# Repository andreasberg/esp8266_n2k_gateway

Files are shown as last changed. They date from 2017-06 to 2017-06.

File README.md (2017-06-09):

# NMEA2000 to WebSocket+Serial gateway 
Reads messages of N2K-bus and relaying over WebSocket and Serial 
### Functionality
- Listens for messages on NMEA 2000 (CANBus) bus and logs PGN of all messages received
- Writes same output over WebSocket and over Serial in Linux-'Tee'-like fashion (WebSocketBufferedStrem.h, inspired by [NeoTee](https://github.com/SlashDevin/NeoTee))
- Parses selected messages and logs
- Provides a simple yet (somewhat) responsive ([BootstrapV3](http://getbootstrap.com/)-based) web interface from the ESP8266 SPIFFS-filesystem
- Web-captive portal for configuration of WiFi-connecition
- Over-The-Air updates supported

### Dependencies
Depends on the following libraries (in addtion to the [`ESP8266 Core`](https://github.com/esp8266/Arduino) and [`Arduino IDE`](https://github.com/arduino/Arduino))
- [`arduinoWebSockets`](https://github.com/Links2004/arduinoWebSockets) - WebSocket Server and Client for Arduino
- [`CAN_BUS_Shield`](https://github.com/peppeve/CAN_BUS_Shield) - Can Bus Mcp2515 8/16 MHz oscillator 
- [`NMEA2000`](https://github.com/ttlappalainen/NMEA2000) - NMEA2000 library for Arduino 
- [`NMEA2000_mcp`](https://github.com/andreasberg/NMEA2000_mcp) - NMEA2000 library support for MCP2515 CAN bus controller. Forked version with added support for ESP8266 interrupts
- [`WiFiManager`](https://github.com/tzapu/WiFiManager) - ESP8266 WiFi Connection manager with web captive portal
- [`Arduino-Makefile-ESP`](https://github.com/andreasberg/Arduino-Makefile-ESP) - Arduino Makefile for ESP-boards 

### Building & flashing 

Edit the Makefile 
```make
  ARDMK_DIR := $(SRCDIR)/../Arduino-Makefile-ESP
  BOARD_TAG=huzzah
  ESP_OTA_ADDR=192.168.12.31
```
Then compile->link->hex
```sh
  make 
```
Normal upload (`esptool`) over USB-serial-FTDI 
```sh
  # first hit GPIO0+RST buttons on the Huzzah-board to enter flash-mode
  make upload 
  # sometimes the boot process hangs after upload, press RST to try again 
```
If the device for the USB-serial port in not detected correctly then override by defining MONITOR_PORT in Makefile
```make
  MONITOR_PORT=/dev/tty.usbserial-A104OFNV
```
A special target `monitor` in the makefile opens a screen-connection over serial
```sh
  make monitor
  # Ctrl-A k let's you terminate the serial connection
  # Connection needs to be terminated before 'make upload' or 'make upload_fs'
```
Once this (or any other sketch supporing Over-The-Air (OTA) updates) is successfully flashed, further uploads can be done with `espota.py` without putting board into flash-mode or closing serial connection(monitor)
Update Makefile:
```make
  ESP_OTA_ADDR=192.168.4.1
  ESP_OTA_PORT=8080           (default 8266)
  ESP_OTA_PWD=mysecret        (default <empty>)
```
and then
```sh
  make upload_ota
```
The webserver-files are located in [$(SRCDIR)/data](data) and the SPIFFS-file (filesystem binary image file) is created with makefile target `fs`
```sh
  make fs
```
and uploaded/flashed with
```sh
  make upload_fs
```
or
```sh
  make upload_fs_ota
```

After the board has booted and connected to Wifi, open a browser and go to `http://<IP>/index.html`

Default WebSocket-port is 81 so clicking 'Connect' shoud open the WebSocket-connection and start the feed of log-messages.

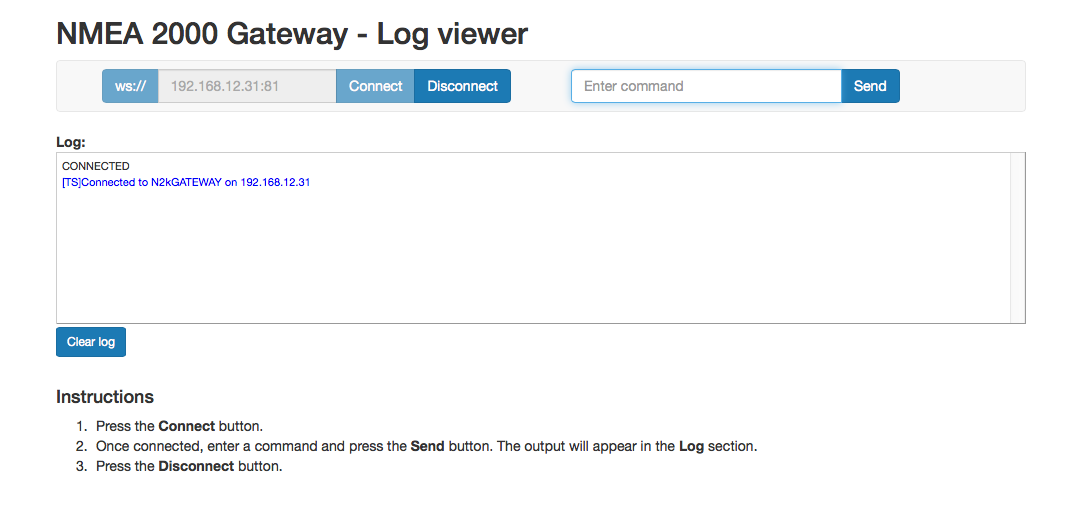
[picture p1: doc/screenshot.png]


### Hardware

The ESP-module used is the [Adafruit HUZZAH ESP8266 breakout](https://learn.adafruit.com/adafruit-huzzah-esp8266-breakout/overview) with a "shield" providing
  - a CAN-bus interface (based on Microchip MCP2515- & MCP2562-ICs)
  - a switching regulator (based on Texas Instrument TPS54202-IC) for powering both the ESP8266-module and shield from the standard 12V supply of NMEA2000 bus

The schematic&board (EAGLE-)files can be found [here](hardware/esp8266_adafruit_huzzah_CAN_shield_with_Regulator)

Components of the shield are hand-solderable (minimum size 0705) but both the inductor (L1) and oscillator (Y1) are a bit tricky (should have a bit larger landing-pads)  

### ToDo/Limitations/Issues

- Implement more generic/lightwigth parse-to-log-function
  - The implementation for parsing the N2k messages is a simple rip of NMEA2000-library DataDisplay-examples and quite heavy. Only a few messages can be handled before exhausting the ESP8266's very limited .text-section (max 32 KB, linker error: section '.text' will not fit in region 'iram1_0_seg'). I assume the WiFiManager & arduinoWebSockets are also to blame for bloating the section. 
- Design shield version 2 for more cost effective ESP8266-modules like the Wemos D1 Mini

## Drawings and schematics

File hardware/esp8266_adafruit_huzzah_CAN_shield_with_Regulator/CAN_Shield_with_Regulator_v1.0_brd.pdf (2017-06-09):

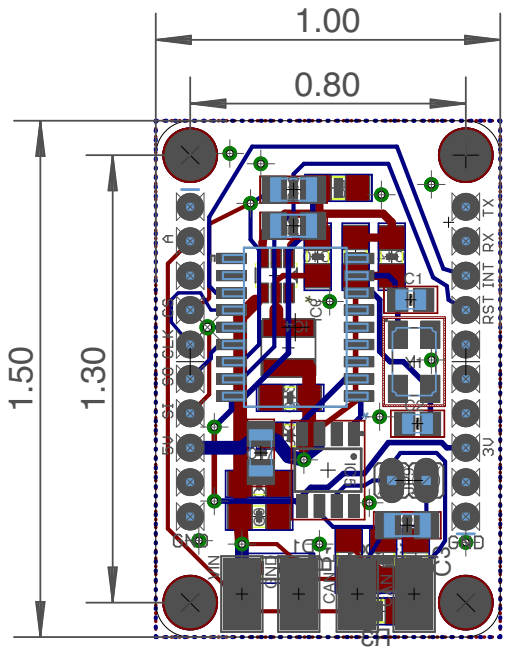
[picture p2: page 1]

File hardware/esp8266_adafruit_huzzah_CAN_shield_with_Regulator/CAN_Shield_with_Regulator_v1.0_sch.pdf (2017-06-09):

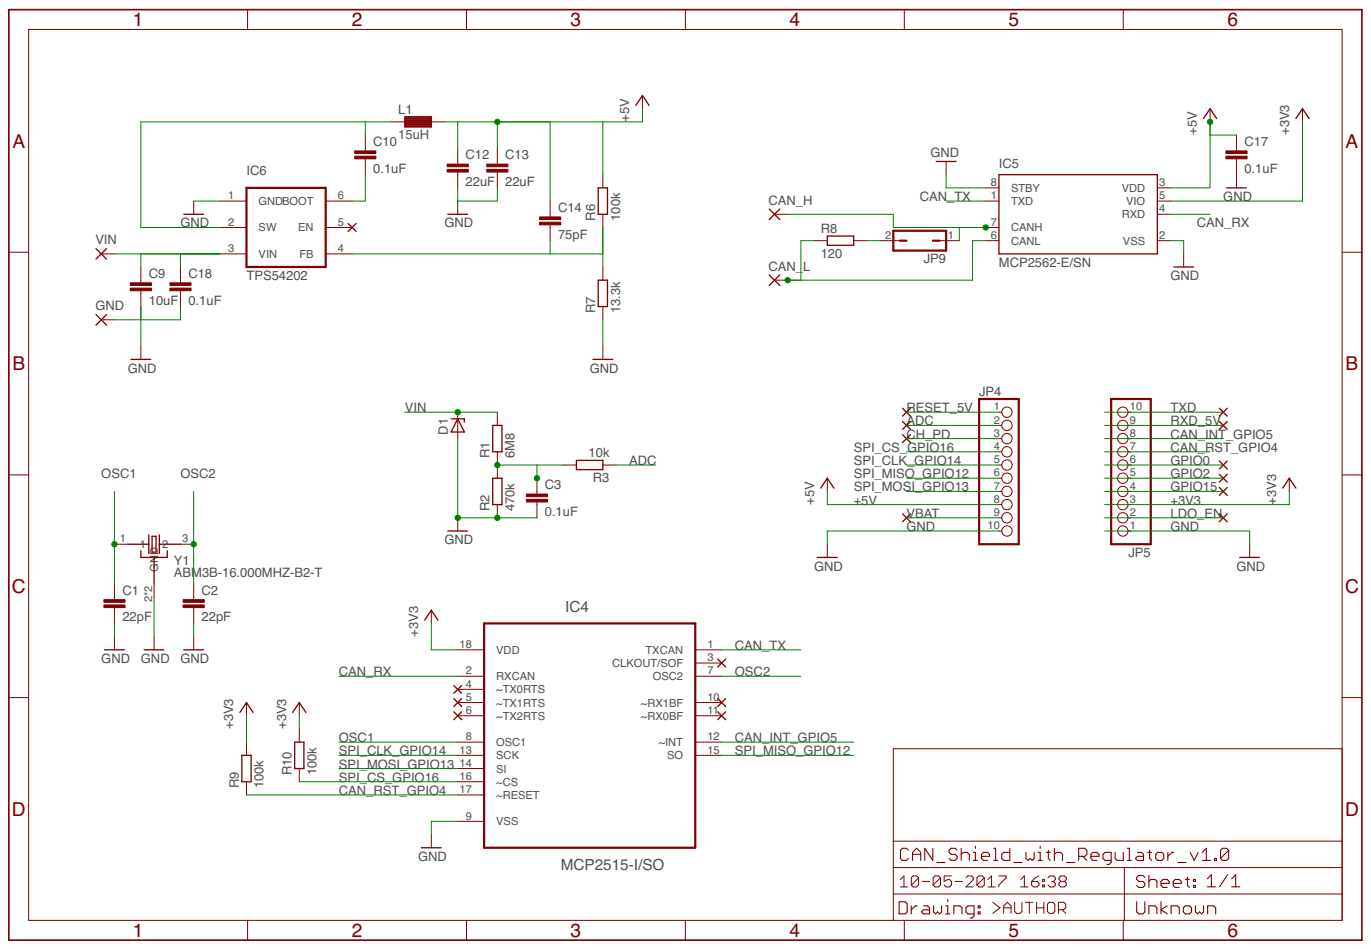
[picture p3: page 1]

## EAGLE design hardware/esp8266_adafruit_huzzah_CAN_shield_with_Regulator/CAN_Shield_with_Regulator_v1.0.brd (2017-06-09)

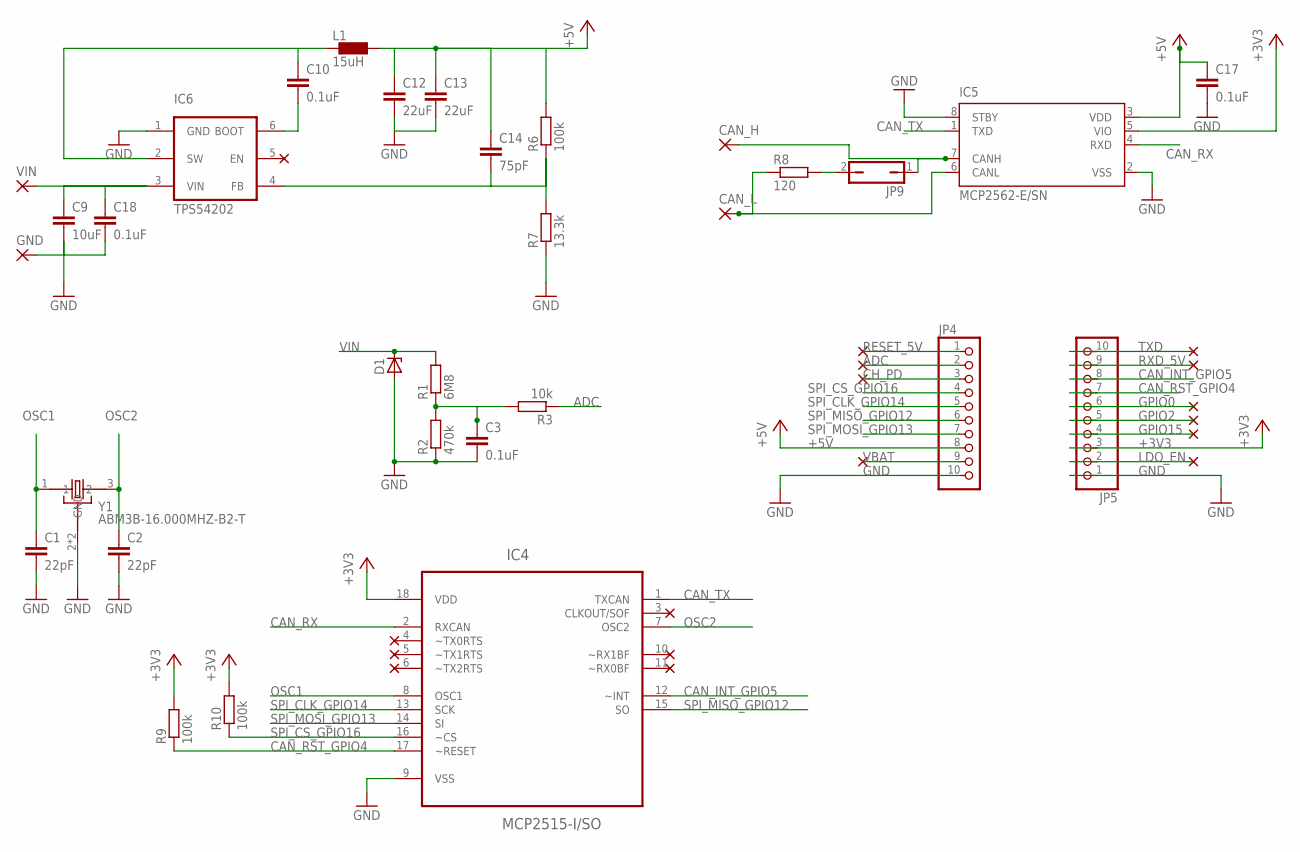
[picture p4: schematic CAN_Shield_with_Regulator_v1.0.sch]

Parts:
C1, C2: 22pF; C0805
C3, C10, C17, C18: 0.1uF; C1206
C9: 10uF; C1206
C12, C13: 22uF; C1206
C14: 75pF; C1206
CAN_H: WIREPADSMD5-2,5; 5-2,5
CAN_L: WIREPADSMD5-2,5; 5-2,5
D1: ZENER-DIODE; SOD3715X135N
GND: WIREPADSMD5-2,5; 5-2,5
IC4: MCP2515-I/SO; SOIC127P1034X264-18N
IC5: MCP2562-E/SN; SOIC127P600X175-8N
IC6: TPS54202; SOT3-6P
JP4, JP5: HEADER-1X1070MIL; 1X10_ROUND70
JP9: JP1Q; JP1
L1: 15uH; ER1515AH
R1: 6M8; R1206
R2: 470k; R1206
R3: 10k; R1206
R6, R9, R10: 100k; R1206
R7: 13.3k; R1206
R8: 120; R1206
VIN: WIREPADSMD5-2,5; 5-2,5
Y1: ABM3B-16.000MHZ-B2-T; OSCSC500X320X110-4N

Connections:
+3V3: IC4.18 (VDD), IC5.5 (VIO), JP5.3, R9.2, R10.2
+5V: C12.1, C13.1, C14.1, C17.1, IC5.3 (VDD), JP4.8, L1.P$1 (1), R6.2
ADC: JP4.2, R3.1
CAN_H: CAN_H.1, IC5.7 (CANH), JP9.1
CAN_INT_GPIO5: IC4.12 (~INT), JP5.8
CAN_L: CAN_L.1, IC5.6 (CANL), R8.1
CAN_RST_GPIO4: IC4.17 (~RESET), JP5.7, R9.1
CAN_RX: IC4.2 (RXCAN), IC5.4 (RXD)
CAN_TX: IC4.1 (TXCAN), IC5.1 (TXD)
CH_PD: JP4.3
GND: C1.2, C2.2, C3.2, C9.2, C12.2, C13.2, C17.2, C18.2, D1.A, GND.1, IC4.9 (VSS), IC5.2 (VSS), IC5.8 (STBY), IC6.1 (GND), JP4.10, JP5.1, R2.1, R7.1, Y1.2 (GND), Y1.4 (GND)
GPIO0: JP5.6
GPIO2: JP5.5
GPIO15: JP5.4
LDO_EN: JP5.2
unnamed: C3.1, R1.1, R2.2, R3.2
unnamed: C10.2, IC6.6 (BOOT)
unnamed: C10.1, IC6.2 (SW), L1.P$2 (2)
unnamed: C14.2, IC6.4 (FB), R6.1, R7.2
unnamed: JP9.2, R8.2
OSC1: C1.1, IC4.8 (OSC1), Y1.1
OSC2: C2.1, IC4.7 (OSC2), Y1.3 (2)
RESET_5V: JP4.1
RXD_5V: JP5.9
SPI_CLK_GPIO14: IC4.13 (SCK), JP4.5
SPI_CS_GPIO16: IC4.16 (~CS), JP4.4, R10.1
SPI_MISO_GPIO12: IC4.15 (SO), JP4.6
SPI_MOSI_GPIO13: IC4.14 (SI), JP4.7
TXD: JP5.10
VBAT: JP4.9
VIN: C9.1, C18.1, D1.C, IC6.3 (VIN), R1.2, VIN.1

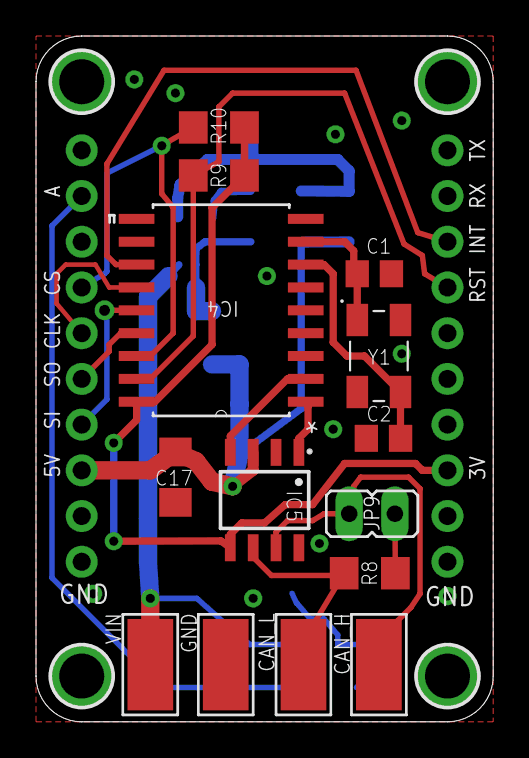
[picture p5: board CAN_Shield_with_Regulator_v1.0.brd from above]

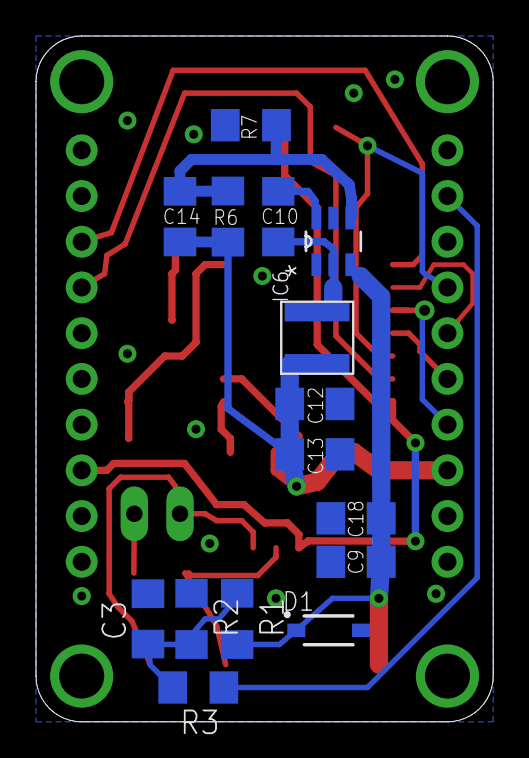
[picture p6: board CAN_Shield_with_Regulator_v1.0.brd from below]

Board: 2 copper layers, 25.4 x 38.1 mm, 36 parts (16 on the bottom side), 22 nets.

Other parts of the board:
E$1, E$2, E$3, E$4: MOUNTINGHOLE_2.5_PLATED
U$23: HUZZAHLOGO

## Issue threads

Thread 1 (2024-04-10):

Compiling for Wemos D1 mini

merco, 2024-04-10:
I get these errors:

In file included from C:\DAVIDE\nmea2000\esp8266_n2k_gateway\esp8266_n2k_gateway.ino:23:
C:\DAVIDE\nmea2000\esp8266_n2k_gateway\WebSocketBufferedStream.h: In member function 'virtual int WebSocketBufferedStream::peek()':
WebSocketBufferedStream.h:382:5: error: no return statement in function returning non-void [-Werror=return-type]
  382 |     }
      |     ^
C:\DAVIDE\nmea2000\esp8266_n2k_gateway\esp8266_n2k_gateway.ino: In function 'void webSocketEvent(uint8_t, WStype_t, uint8_t*, size_t)':
esp8266_n2k_gateway:108:92: error: cannot bind non-const lvalue reference of type 'String&' to an rvalue of type 'String'
  108 |             websock.sendTXT(num, "Connected to N2kGATEWAY on " + WiFi.localIP().toString() + "\n");
      |                                  ~~~~~~~~~~~~~~~~~~~~~~~~~~~~~~~~~~~~~~~~~~~~~~~~~~~~~~~~~~^~~~~~
In file included from C:\DAVIDE\nmea2000\esp8266_n2k_gateway\esp8266_n2k_gateway.ino:13:
C:\Users\mercanti\Documents\Arduino\libraries\WebSockets\src/WebSocketsServer.h:67:40: note:   initializing argument 2 of 'bool WebSocketsServer::sendTXT(uint8_t, String&)'
   67 |     bool sendTXT(uint8_t num, String & payload);
      |                               ~~~~~~~~~^~~~~~~
cc1plus.exe: some warnings being treated as errors
Più di una libreria trovata per "ESP8266WebServer.h"
Usata: C:\Users\mercanti\AppData\Local\Arduino15\packages\esp8266\hardware\esp8266\3.1.2\libraries\ESP8266WebServer
Non usata: C:\Users\mercanti\Documents\Arduino\libraries\WebServer-esp32-master

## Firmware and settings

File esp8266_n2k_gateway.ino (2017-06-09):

// Demo: NMEA2000 library. 
// This demo reads messages from NMEA 2000 bus and
// sends them translated to clear text to Serial.

// Modified for use with the CAN SPI click-board from MikroElektronika
// The CAN SPI click has a 10Mhz oscillator so the USE_MCP_CAN_CLOCK_SET 
// Requires the following modified libraries (in addition to the dependencies of the original example):
// https://github.com/andreasberg/NMEA2000_mcp.git
// https://github.com/andreasberg/CAN_BUS_Shield.git

#include <Arduino.h>
#include <FS.h>
#include <WebSocketsServer.h>
#include <ESP8266WiFi.h>
#include <ESP8266WebServer.h>
#include <ESP8266mDNS.h>
#include <Hash.h>
#include <WiFiManager.h>        //https://github.com/tzapu/WiFiManager
#include <WiFiUdp.h>
#include <ArduinoOTA.h>

//#include "WebSocketStream.h"
#include "WebSocketBufferedStream.h"
//#include <Time.h>  // 

// Beware, the following constants MUST be defined before including NMEA2000_CAN.h
#define N2k_SPI_CS_PIN 16  // Pin for SPI Can Select
#define N2k_CAN_INT_PIN 5 // Use interrupt  and it is connected to pin 4
#define USE_MCP_CAN_CLOCK_SET 16  // possible values 8 for 8Mhz and 16 for 16 Mhz clock, 10 for 10MHz clock
#define MCP_CAN_RX_BUFFER_SIZE 10

// set the n2kSourceId to a unique number on the NMEA2000 bus
const uint8_t n2kSourceId = 36;

#include <NMEA2000_CAN.h>
#include <N2kMessages.h>
#include <N2kMessagesEnumToStr.h>

typedef struct {
  unsigned long PGN;
  void (*Handler)(const tN2kMsg &N2kMsg); 
} tNMEA2000Handler;

//#define N2K_ERROR_NOHANDLER "No handler"
static const char N2K_ERROR_NOHANDLER[] PROGMEM = "No handler";
static const char N2K_ERROR_PARSE[] PROGMEM = "Failed to parse message";


//void SystemTime(const tN2kMsg &N2kMsg);
void EngRapid(const tN2kMsg &N2kMsg);
void EngDynParams(const tN2kMsg &N2kMsg);
// // void ICACHE_FLASH_ATTR TransmissionParameters(const tN2kMsg &N2kMsg);
// // void ICACHE_FLASH_ATTR WaterDepth(const tN2kMsg &N2kMsg);
// // void ICACHE_FLASH_ATTR FluidLevel(const tN2kMsg &N2kMsg);
// // void ICACHE_FLASH_ATTR OutsideEnvironmental(const tN2kMsg &N2kMsg);
// // void ICACHE_FLASH_ATTR Temperature(const tN2kMsg &N2kMsg);
// // void ICACHE_FLASH_ATTR TemperatureExt(const tN2kMsg &N2kMsg);
// // void ICACHE_FLASH_ATTR DCStatus(const tN2kMsg &N2kMsg);
// // void ICACHE_FLASH_ATTR BatteryConfigurationStatus(const tN2kMsg &N2kMsg);
void COGSOG(const tN2kMsg &N2kMsg);
void GNSS(const tN2kMsg &N2kMsg);
void Attitude(const tN2kMsg &N2kMsg);
// // void ICACHE_FLASH_ATTR Heading(const tN2kMsg &N2kMsg);
// void Position(const tN2kMsg &N2kMsg);
void HandleN2kMsg(const tN2kMsg &N2kMsg);

tNMEA2000Handler N2kHandlers[]={
//   {126992L,&SystemTime},
// //  {127250L,&Heading},
   {127257L,&Attitude},
   {127488L,&EngRapid},
   {127489L,&EngDynParams},
// //  {127493L,&TransmissionParameters},
// //  {127505L,&FluidLevel},
// //  {127506L,&DCStatus},
// //  {127513L,&BatteryConfigurationStatus},
// //  {128267L,&WaterDepth},
   //{129025L,&Position},
   // {129026L,&COGSOG},
   //{129029L,&GNSS},
// //  {130310L,&OutsideEnvironmental},
// //  {130312L,&Temperature},
// //  {130316L,&TemperatureExt},
  {0,0}
};


ESP8266WebServer websrv = ESP8266WebServer(80);
WebSocketsServer websock = WebSocketsServer(81);
WiFiManager wifiManager;

//Stream *OutputStream = &Serial;
//WebSocketStream *OutputStream;
WebSocketBufferedStream *OutputStream;

void webSocketEvent(uint8_t num, WStype_t type, uint8_t * payload, size_t len) {

    switch(type) {
        case WStype_DISCONNECTED:
            Serial.printf("[%u] Disconnected!\n", num);
            break;
        case WStype_CONNECTED: {
            IPAddress ip = websock.remoteIP(num);
            Serial.printf("[%u] Connected from %d.%d.%d.%d url: %s\n", num, ip[0], ip[1], ip[2], ip[3], payload);

            // send message to client
            //websock.sendTXT(num, "Connected");
            websock.sendTXT(num, "Connected to N2kGATEWAY on " + WiFi.localIP().toString() + "\n");
        }
            break;
        case WStype_TEXT:
            Serial.printf("[Client %u] Got command: %s\n", num, payload);
            if (strcmp((char *)payload, "RESETWIFI")==0) {
              Serial.printf("Resetting Wifi \n", num, payload);
              wifiManager.resetSettings();
              delay(3000);
              ESP.reset();
              delay(5000);
            }
            // Echo to serial and back to websocket
            //OutputStream->print(payload,len);
            // TODO: do something

            break;
    }

}

void setup() {

  Serial.begin(115200);
  while (!Serial) 
    delayMicroseconds(200000);
  delayMicroseconds(2000000);

  Serial.println();
  Serial.print( F("Heap: ") ); Serial.println(system_get_free_heap_size());
  Serial.print( F("Boot Vers: ") ); Serial.println(system_get_boot_version());
  Serial.print( F("CPU: ") ); Serial.println(system_get_cpu_freq());
  Serial.print( F("SDK: ") ); Serial.println(system_get_sdk_version());
  Serial.print( F("Chip ID: ") ); Serial.println(system_get_chip_id());
  Serial.print( F("Flash ID: ") ); Serial.println(spi_flash_get_id());
  Serial.print( F("Flash Size: ") ); Serial.println(ESP.getFlashChipRealSize());
  Serial.print( F("Vcc: ") ); Serial.println(ESP.getVcc());
  Serial.println();

  //wifiManager.resetSettings();

  ArduinoOTA.onStart([]() {
    Serial.println(F("Start"));
  });
  ArduinoOTA.onEnd([]() {
    Serial.println(F("\nEnd"));
  });
  ArduinoOTA.onProgress([](unsigned int progress, unsigned int total) {
    Serial.printf("Progress: %u%%\r", (progress / (total / 100)));
  });
  ArduinoOTA.onError([](ota_error_t error) {
    Serial.printf("Error[%u]: ", error);
    if (error == OTA_AUTH_ERROR) Serial.println(F("Auth Failed"));
    else if (error == OTA_BEGIN_ERROR) Serial.println(F("Begin Failed"));
    else if (error == OTA_CONNECT_ERROR) Serial.println(F("Connect Failed"));
    else if (error == OTA_RECEIVE_ERROR) Serial.println(F("Receive Failed"));
    else if (error == OTA_END_ERROR) Serial.println(F("End Failed"));
  });
  ArduinoOTA.begin();

  delay(2000);

  Serial.println(F("Starting Filesystem..."));
  SPIFFS.begin();
  {
    Dir dir = SPIFFS.openDir("/");
    while (dir.next()) {
      String fileName = dir.fileName();
      size_t fileSize = dir.fileSize();
      Serial.printf("FS File: %s, size: %s\n", fileName.c_str(), String(fileSize).c_str());
    }
    Serial.printf("\n");
  }
 
  Serial.println(F("Starting N2k/CAN BUS..."));
   
  // Do not forward bus messages at all
  NMEA2000.SetForwardType(tNMEA2000::fwdt_Text);
  NMEA2000.SetForwardStream(OutputStream);
  NMEA2000.SetMode(tNMEA2000::N2km_ListenAndNode,n2kSourceId);
  // Set false below, if you do not want to see messages parsed to HEX withing library
  NMEA2000.EnableForward(false);
  NMEA2000.SetMsgHandler(HandleN2kMsg);
  NMEA2000.SetN2kCANMsgBufSize(2);
  NMEA2000.Open();

  Serial.println(F("Starting WiFi..."));
  
  Serial.printf("ESP8266 Chip id = %08X\n", ESP.getChipId());
  char hostname_and_ssid[20];
  sprintf(hostname_and_ssid,"N2kGATEWAY-%08X",ESP.getChipId());
  Serial.print(F("Setting Hostname & SSID = "));Serial.println(hostname_and_ssid);
  WiFi.hostname(hostname_and_ssid);

  
  
  if (!wifiManager.autoConnect(hostname_and_ssid)) {
    Serial.println(F("failed to connect, we should reset as see if it connects"));
    delay(3000);
    ESP.reset();
    delay(5000);
  }

  delay(5000);

  Serial.print(F("[SETUP] Connected, IP: "));
  Serial.println(WiFi.localIP());

  // start webSocket server
  Serial.println(F("[SETUP] Starting WebSocket server..."));
  websock.begin();
  websock.onEvent(webSocketEvent);


  OutputStream = new WebSocketBufferedStream(&websock,&Serial);   // Combine webSocket and Serial in one WebSocketStream, print-calls to stream writes to both Serial and WebSocket
  
  OutputStream->println(F("[SETUP] Starting mDNS responder..."));
  if(MDNS.begin("esp8266")) {
    OutputStream->println(F("[SETUP] MDNS responder started"));
  }

  // handle index
  //websrv.on("/", []() {
      // send index.html
      //websrv.send(200, "text/html", "<html><head><script>var connection = new WebSocket('ws://'+location.hostname+':81/', ['arduino']);connection.onopen = function () {  connection.send('Connect ' + new Date()); }; connection.onerror = function (error) {    console.log('WebSocket Error ', error);};connection.onmessage = function (e) {  console.log('Server: ', e.data);};function sendRGB() {  var r = parseInt(document.getElementById('r').value).toString(16);  var g = parseInt(document.getElementById('g').value).toString(16);  var b = parseInt(document.getElementById('b').value).toString(16);  if(r.length < 2) { r = '0' + r; }   if(g.length < 2) { g = '0' + g; }   if(b.length < 2) { b = '0' + b; }   var rgb = '#'+r+g+b;    console.log('RGB: ' + rgb); connection.send(rgb); }</script></head><body>LED Control:<br/><br/>R: <input id=\"r\" type=\"range\" min=\"0\" max=\"255\" step=\"1\" oninput=\"sendRGB();\" /><br/>G: <input id=\"g\" type=\"range\" min=\"0\" max=\"255\" step=\"1\" oninput=\"sendRGB();\" /><br/>B: <input id=\"b\" type=\"range\" min=\"0\" max=\"255\" step=\"1\" oninput=\"sendRGB();\" /><br/></body></html>");
  //    websrv.send(200, "text/html", "<html><head><title>Web Socket Logger</title></head><body><form onsubmit=\"return false;\"><h3>Serial Monitor</h3><label>ESP8266 WebSocket Serial Proxy Host</label><input type=\"text\" id=\"host\" value=\"\" style=\"width:160px;\" placeholder=\"ws://hostname:port/ws\"/><input type=\"button\" value=\"Connect\" onclick=\"connect(host.value)\" /><br><label>Connection Status:</label><input type=\"text\" id=\"connectionLabel\" readonly=\"true\" value=\"Idle\"/><br /><br><textarea id=\"output\" style=\"width:100%;height:500px;\"></textarea><br><input type=\"button\" value=\"Clear\" onclick=\"clearText()\"></form><script type=\"text/javascript\">const PING_INTERVAL_MILLIS = 5000;var output = document.getElementById('output');var connectionLabel = document.getElementById('connectionLabel');var socket;function connect(host) {console.log('connect', host); if (window.WebSocket) {connectionLabel.value = 'Connecting';if(socket) {socket.close();socket = null;} socket = new WebSocket(host); socket.onmessage = function(event) {output.value += event.data; var textarea = document.getElementById('output');textarea.scrollTop=textarea.scrollHeight;}; socket.onopen = function(event) {isRunning = true;connectionLabel.value = 'Connected';}; socket.onclose = function(event) {isRunning = false; connectionLabel.value='Disconnected'; }; socket.onerror = function(event) {connectionLabel.value = 'Error';};} else {alert('Your browser does not support Web Socket.');}} function send(data) {if (!window.WebSocket) { return; } if (socket.readyState == WebSocket.OPEN) { var message = data; output.value += 'sending : ' + data + '\\\r\\\n'; socket.send(message); } else { alert('The socket is not open.'); }} function clearText() { output.value=''; }</script></body></html>");
  //});

  OutputStream->printf("[SETUP] Starting web server...\n");
  websrv.serveStatic("/index.html", SPIFFS, "/n2kgw.html");
  websrv.serveStatic("/fonts", SPIFFS, "/fonts", "max-age=86400");
  websrv.serveStatic("/js", SPIFFS, "/js");
  websrv.serveStatic("/css", SPIFFS, "/css", "max-age=86400");
  websrv.serveStatic("/images", SPIFFS, "/images", "max-age=86400");
  websrv.serveStatic("/", SPIFFS, "/n2kgw.html");  
  websrv.begin();

  // Add service to MDNS
  MDNS.addService("http", "tcp", 80);
  MDNS.addService("ws", "tcp", 81);

  delay(2000);

  OutputStream->print("Running...\n");
}

//*****************************************************************************
//const __FlashStringHelper*
//const char*
// PrintLabelValWithConversionCheckUnDef -> PrintLblVal
template<typename T> void PrintLabelValWithConversionCheckUnDef(const __FlashStringHelper* label, T val, double (*ConvFunc)(double val)=0, bool AddLf=false ) {
  char notavailable[] = "not available";
  OutputStream->printf_P((PGM_P)label);
  if (!N2kIsNA(val)) {
    if (ConvFunc) { OutputStream->print(ConvFunc(val)); } else { OutputStream->print(val); }
  } else OutputStream->print(notavailable);
  if (AddLf) OutputStream->println();
}

// //*****************************************************************************
// void SystemTime(const tN2kMsg &N2kMsg) {
//     unsigned char SID;
//     uint16_t SysDate;
//     double SysTime;
//     tN2kTimeSource TimeSrc;
    
//     if (ParseN2kSystemTime(N2kMsg,SID,SysDate,SysTime,TimeSrc) ) {
//       PrintLabelValWithConversionCheckUnDef(F("System time - days since 1.1.1970: "),SysDate,0,false);
//       PrintLabelValWithConversionCheckUnDef(F(" seconds since midnight: "),SysTime,0,false);
//                         OutputStream->print(F(" time source: ")); PrintN2kEnumType(TimeSrc,OutputStream);
//     } else {
//       OutputStream->println(F("N2K_ERROR_PARSE")); 
//     }
//     OutputStream->flush();
// }

//*****************************************************************************
void EngRapid(const tN2kMsg &N2kMsg) {
    unsigned char EngineInstance;
    double EngineSpeed;
    double EngineBoostPressure;
    int8_t EngineTiltTrim;
    
    if (ParseN2kEngineParamRapid(N2kMsg,EngineInstance,EngineSpeed,EngineBoostPressure,EngineTiltTrim) ) {
      PrintLabelValWithConversionCheckUnDef(F("Engine rapid params: "),EngineInstance,0,false);
      PrintLabelValWithConversionCheckUnDef(F(" RPM: "),EngineSpeed,0,false);
      PrintLabelValWithConversionCheckUnDef(F(" boost pressure (Pa): "),EngineBoostPressure,0,false);
      PrintLabelValWithConversionCheckUnDef(F(" tilt trim: "),EngineTiltTrim,0,true);
    } else {
      OutputStream->println(N2K_ERROR_PARSE);

    }
    OutputStream->flush();
}

//*****************************************************************************
void EngDynParams(const tN2kMsg &N2kMsg) {
    unsigned char Inst;
    double OilPress;
    double OilTemp;
    double CoolantTemp;
    double Voltage;
    double FuelRate;
    double EngineHours;
    double CoolantPress;
    double FuelPress; 
    int8_t Load;
    int8_t Torque;
    if (ParseN2kEngineDynamicParam(N2kMsg,Inst,OilPress,OilTemp,CoolantTemp,
                                   Voltage,FuelRate,EngineHours,
                                   CoolantPress,FuelPress,
                                   Load,Torque) ) {
      PrintLabelValWithConversionCheckUnDef(F("Engine "),Inst,0,false);
      PrintLabelValWithConversionCheckUnDef(F(" Oil pressure(Pa): "),OilPress,0,false);
      PrintLabelValWithConversionCheckUnDef(F(" Oil temp(C): "),OilTemp,&KelvinToC,false);
      PrintLabelValWithConversionCheckUnDef(F(" Coolant temp(C): "),CoolantTemp,&KelvinToC,false);
      PrintLabelValWithConversionCheckUnDef(F(" Altenator voltage(V): "),Voltage,0,false);
      PrintLabelValWithConversionCheckUnDef(F(" Fuel rate(l/h): "),FuelRate,0,false);
      PrintLabelValWithConversionCheckUnDef(F(" Engine hours (h): "),EngineHours,&SecondsToh,false);
      PrintLabelValWithConversionCheckUnDef(F(" Coolant pres (Pa): "),CoolantPress,0,false);
      PrintLabelValWithConversionCheckUnDef(F(" Fuel pressure (Pa): "),FuelPress,0,false);
      PrintLabelValWithConversionCheckUnDef(F(" Engine load (%): "),Load,0,false);
      PrintLabelValWithConversionCheckUnDef(F(" Engine torque (%): "),Torque,0,true);
    } else {
      OutputStream->println(N2K_ERROR_PARSE);
    }
    OutputStream->flush();
}

// //*****************************************************************************
// void ICACHE_FLASH_ATTR TransmissionParameters(const tN2kMsg &N2kMsg) {
//     unsigned char EngineInstance;
//     tN2kTransmissionGear TransmissionGear;
//     double OilPressure;
//     double OilTemperature;
//     unsigned char DiscreteStatus1;
    
//     if (ParseN2kTransmissionParameters(N2kMsg,EngineInstance, TransmissionGear, OilPressure, OilTemperature, DiscreteStatus1) ) {
//       PrintLabelValWithConversionCheckUnDef("Transmission params: ",EngineInstance,0,true);
//                         OutputStream->print("  gear: "); PrintN2kEnumType(TransmissionGear,OutputStream);
//       PrintLabelValWithConversionCheckUnDef("  oil pressure (Pa): ",OilPressure,0,true);
//       PrintLabelValWithConversionCheckUnDef("  oil temperature (C): ",OilTemperature,&KelvinToC,true);
//       PrintLabelValWithConversionCheckUnDef("  discrete status: ",DiscreteStatus1,0,true);
//     } else {
//       OutputStream->print("Failed to parse PGN: "); OutputStream->println(N2kMsg.PGN);
//     }
// }

// //*****************************************************************************
// void ICACHE_FLASH_ATTR Heading(const tN2kMsg &N2kMsg) {
//     unsigned char SID;
//     tN2kHeadingReference HeadingReference;
//     double Heading;
//     double Deviation;
//     double Variation;
    
//     if (ParseN2kHeading(N2kMsg,SID,Heading,Deviation,Variation,HeadingReference) ) {
//       PrintLabelValWithConversionCheckUnDef(F("Heading: "),SID,0,false);
//                         OutputStream->print(F(" reference: ")); PrintN2kEnumType(HeadingReference,OutputStream,false);
//       PrintLabelValWithConversionCheckUnDef(F(" Heading (deg): "),Heading,&RadToDeg,false);
//       PrintLabelValWithConversionCheckUnDef(F(" Deviation (deg): "),Deviation,&RadToDeg,false);
//       PrintLabelValWithConversionCheckUnDef(F(" Variation (deg): "),Variation,&RadToDeg,true);
//     } else {
//       OutputStream->print(F("Failed to parse PGN: ")); OutputStream->println(N2kMsg.PGN);
//     }
//     OutputStream->flush();
// }


// //*****************************************************************************
// void Position(const tN2kMsg &N2kMsg) {
//     double Latitude;
//     double Longitude;
    
//     if (ParseN2kPositionRapid(N2kMsg,Latitude,Longitude) ) {
//       PrintLabelValWithConversionCheckUnDef(F("Position: Latitude: "),Latitude,0,false);
//       PrintLabelValWithConversionCheckUnDef(F(" Longitude: "),Longitude,0,true);
//     } else {
//       OutputStream->print(N2K_ERROR_PARSE); 
//     }
//     OutputStream->flush();
// }


// //*****************************************************************************
// void COGSOG(const tN2kMsg &N2kMsg) {
//     unsigned char SID;
//     tN2kHeadingReference HeadingReference;
//     double COG;
//     double SOG;
    
//     if (ParseN2kCOGSOGRapid(N2kMsg,SID,HeadingReference,COG,SOG) ) {
//       PrintLabelValWithConversionCheckUnDef(F("COG/SOG: COG(deg): "),COG,&RadToDeg,false);
//       PrintLabelValWithConversionCheckUnDef(F(" SOG (m/s): "),SOG,0,false);
//       //OutputStream->print(F(" reference: ")); PrintN2kEnumType(HeadingReference,OutputStream);
//     } else {
//       OutputStream->println(N2K_ERROR_PARSE); 
//     }
//     OutputStream->flush();
// }



//*****************************************************************************
void GNSS(const tN2kMsg &N2kMsg) {
    unsigned char SID;
    uint16_t Days;
    double Secs; 
    double Lat;
    double Long;
    double Alti; 
    tN2kGNSStype GNSSt;
    tN2kGNSSmethod GNSSm;
    unsigned char nSat;
    double HDOP;
    double PDOP;
    double GeoSep;
    unsigned char nRefStat;
    tN2kGNSStype RefStatType;
    uint16_t RefStatID;
    double AgeOfCorr;

    if (ParseN2kGNSS(N2kMsg,SID,Days,Secs,
                  Lat,Long,Alti,
                  GNSSt,GNSSm,
                  nSat,HDOP,PDOP,GeoSep,
                  nRefStat,RefStatType,RefStatID,
                  AgeOfCorr) ) {
      PrintLabelValWithConversionCheckUnDef(F("GNSS info: days since 1.1.1970: "),Days,0,false);
      PrintLabelValWithConversionCheckUnDef(F("  seconds since midnight: "),Secs,0,false);
      PrintLabelValWithConversionCheckUnDef(F("  latitude: "),Lat,0,false);
      PrintLabelValWithConversionCheckUnDef(F("  longitude: "),Long,0,false);
      PrintLabelValWithConversionCheckUnDef(F("  altitude: (m): "),Alti,0,false);
      PrintLabelValWithConversionCheckUnDef(F("  satellite count: "),nSat,0,false);
      PrintLabelValWithConversionCheckUnDef(F("  HDOP: "),HDOP,0,false);
      PrintLabelValWithConversionCheckUnDef(F("  PDOP: "),PDOP,0,false);
      PrintLabelValWithConversionCheckUnDef(F("  geoidal separation: "),GeoSep,0,false);
      PrintLabelValWithConversionCheckUnDef(F("  reference stations: "),nRefStat,0,false);
                         OutputStream->print(F("  GNSS type: ")); PrintN2kEnumType(GNSSt,OutputStream,false);
      //                   OutputStream->print(F("  GNSS method: ")); PrintN2kEnumType(GNSSm,OutputStream);
    } else {
      OutputStream->println(N2K_ERROR_PARSE); 
    }
    OutputStream->flush();
}

// //*****************************************************************************
// void ICACHE_FLASH_ATTR OutsideEnvironmental(const tN2kMsg &N2kMsg) {
//     unsigned char SID;
//     double WaterTemperature;
//     double OutsideAmbientAirTemperature;
//     double AtmosphericPressure;
    
//     if (ParseN2kOutsideEnvironmentalParameters(N2kMsg,SID,WaterTemperature,OutsideAmbientAirTemperature,AtmosphericPressure) ) {
//       PrintLabelValWithConversionCheckUnDef("Water temp: ",WaterTemperature,&KelvinToC);
//       PrintLabelValWithConversionCheckUnDef(", outside ambient temp: ",OutsideAmbientAirTemperature,&KelvinToC);
//       PrintLabelValWithConversionCheckUnDef(", pressure: ",AtmosphericPressure,0,true);
//     } else {
//       OutputStream->print("Failed to parse PGN: ");  OutputStream->println(N2kMsg.PGN);
//     }
// }

// //*****************************************************************************
// void ICACHE_FLASH_ATTR Temperature(const tN2kMsg &N2kMsg) {
//     unsigned char SID;
//     unsigned char TempInstance;
//     tN2kTempSource TempSource;
//     double ActualTemperature;
//     double SetTemperature;
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
void loop() {
  NMEA2000.ParseMessages();
  websock.loop();
  websrv.handleClient();
  ArduinoOTA.handle();
}

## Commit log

2017-06-08 Simpler implementation of WebSocket+Stream “Tee”-function by buffering single character writes before flushing to WebSocket
2017-06-08 Changed WebSocket “Tee”-function
2017-06-09 Changed Makefile-framework from makeEspArduino to Arduino-Makefile-ESP
2017-06-09 Added EAGLE-files for the CANBus Shield used by the esp8266_n2k_gateway
    [CAN_Shield_with_Regulator_v1.0.brd, CAN_Shield_with_Regulator_v1.0.sch]
2017-06-09 Added pdfs of board and schematic

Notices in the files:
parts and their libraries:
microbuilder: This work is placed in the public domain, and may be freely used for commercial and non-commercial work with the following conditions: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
